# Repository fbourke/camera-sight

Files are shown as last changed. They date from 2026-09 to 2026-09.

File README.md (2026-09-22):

# camera-sight

A 3D-printed open-frame "rifle sight" for a 35 mm cine camera, written in
[OpenSCAD](https://openscad.org/). You look through the rear ring at the front
ring; when the two rings nest concentrically your eye is at the design eye
relief, and the front opening then frames exactly what the lens sees.

The frame is derived from the camera gate (35 mm 4-perf Academy, SMPTE 59) and
the lens focal length, so one file covers every lens: change `f_lens` and
export.

## Mounting

Two clearance holes on the side wall take the finder screws of a Bell & Howell
Eyemo: 0.125" screws on 0.918" centres, set a third of the way back from the
front face. The screws thread into the camera; the sight only needs to clear
them.

The original cold-shoe foot is still in the file behind `with_foot` if you
want it instead.

## Usage

Open `rifle_sight.scad` and set the knobs at the top of the file:

| Parameter | What it does |
| --- | --- |
| `f_lens` | Lens focal length in mm. Sets the frame size and the engraved label. |
| `eye_relief` | Distance from your pupil to the rear face, mm. |
| `with_foot`, `mount_side` | Add the cold-shoe foot, and whether it stands beside or lies under the sight. |
| `label_top` | Engrave the focal length on the top wall (`true`) or the bottom (`false`). |
| `quick` | Skip the filleted body for a faster preview. |

Then render (F6) and export an STL. From the command line:

```sh
openscad -D f_lens=50 -o rifle_sight_50mm.stl rifle_sight.scad
```

The console echoes the frame size and the field of view it subtends, which is
a handy sanity check against the lens.

## Printing

Print with the rear (eye) face down. The webs carrying the front reticle are
angled so their steepest overhang is `90 - a_gusset + a_concave` degrees (65
by default), which prints without support.

Ready-made STLs for 28, 35 and 50 mm lenses are in the repo.

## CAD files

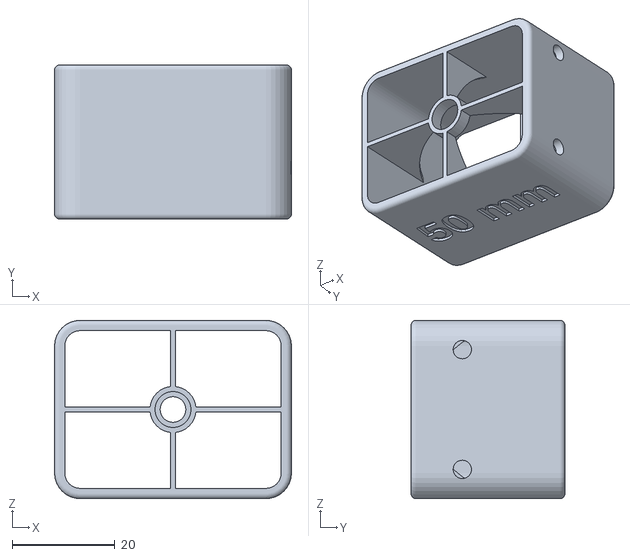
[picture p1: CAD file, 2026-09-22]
rifle_sight_eyemo_50mm.stl
46.1 x 30.0 x 34.7

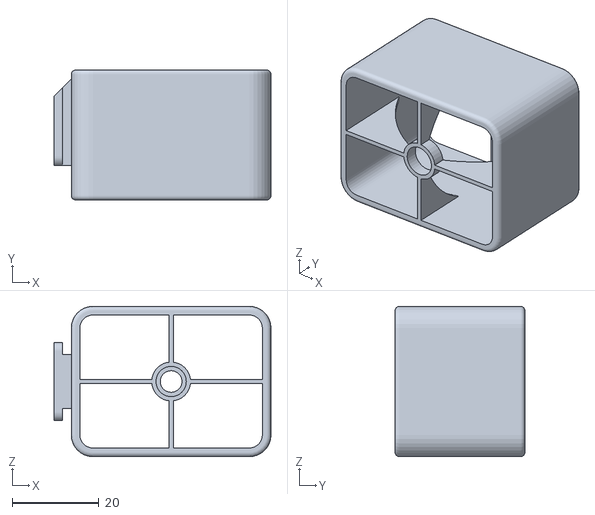
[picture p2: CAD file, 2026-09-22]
rifle_sight_50mm.stl
50.1 x 30.0 x 34.7

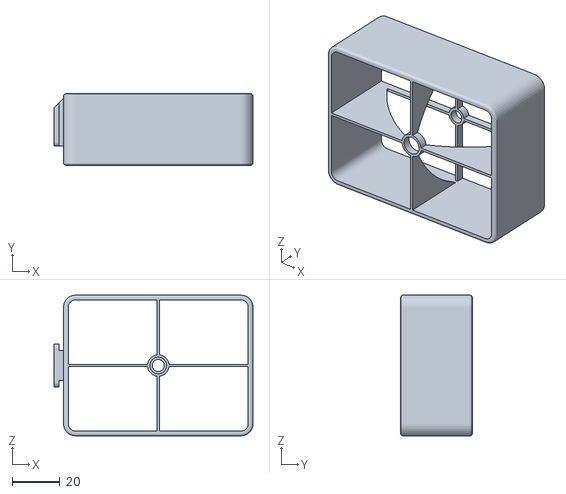
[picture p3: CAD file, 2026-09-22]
rifle_sight_28mm.stl
83.2 x 30.0 x 58.9

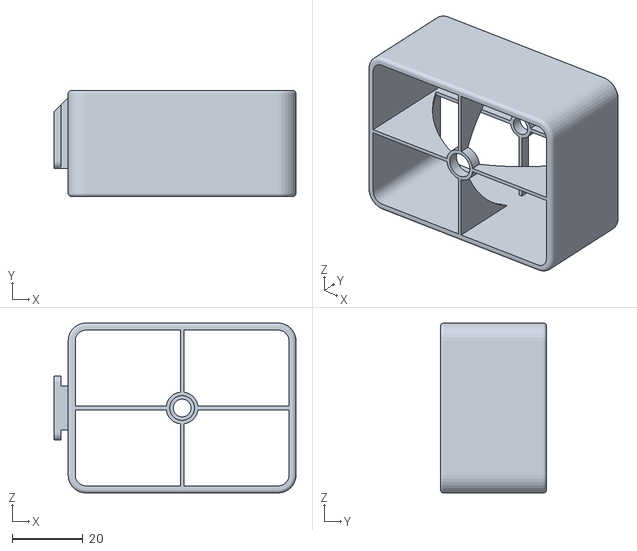
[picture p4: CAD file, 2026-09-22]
rifle_sight_35mm.stl
68.2 x 30.0 x 47.9

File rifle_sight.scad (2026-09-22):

$fn = 32;

quick = false;

// Format: 35 mm 4-perf, Academy camera aperture (SMPTE 59), 1.372:1.
gate_w = 21.95;
gate_h = 16.00;
f_lens = 50;

// Pupil to the rear face. The only ergonomic knob: frame size and front ring both
// scale off it. 66 is what the original 2.5/3.5 ring pair already implied.
eye_relief = 66;

l_sight = 30;
th_sight = 2;
l_offset_sight = l_sight/2 - 12;

// The front opening is the frame, so it must subtend the lens' field from the eye.
// The rear opening is the same size but nearer, so it subtends more and never clips.
d_frame = eye_relief + l_sight;
w_sight = gate_w * d_frame / f_lens;
h_sight = gate_h * d_frame / f_lens;

w_crosshairs = 1;
l_crosshairs = 3;
aperture_r = 2.5;
// Sized so both rings subtend the same angle at the design eye position: they nest
// concentrically only there, which is what holds eye_relief (and the framing) honest.
aperture_f = aperture_r * (d_frame - l_crosshairs/2) / (eye_relief + l_crosshairs/2);

r_fillet = 1;
r_inner_sight = 3;
r_outer_sight = r_inner_sight + th_sight;

// Straight run of the webs under the front reticle, printing rear face down, and how
// far their edge bows in from it. Steepest overhang is 90 - a_gusset + a_concave, so
// a_concave = 0 is a straight 45 deg web and 45 puts the edge tangent to the arm.
a_gusset = 45;
a_concave = 20;

// Cold shoe foot, superseded by the Eyemo holes but kept as an option. Wall it mounts
// on: side stands the plate vertical alongside the sight, otherwise it lies flat
// underneath.
with_foot = false;
mount_side = false;

w_foot = 18.1;
l_foot = 20;
h_foot = 1.99;
r_foot = 2;

w_leg = 12.5;
h_leg = 2;

// Eyemo finder mount: two clearance holes through the side wall away from the shoe,
// one either side of the axis, the pair set l_mount back from the front face. Screws
// thread into the camera, so the holes only need to clear the 0.125" major diameter.
d_mount_screw = 0.125 * 25.4;
d_mount_hole = d_mount_screw + 0.4;
p_mount = 0.918 * 25.4;
l_mount = l_sight/3;

// Focal length engraved in the top wall, reading left to right from the eye. Bottom
// instead puts it where it reads the same way once the sight is turned over.
label_top = false;
s_label = 8;
d_label = 0.6;

echo (str ("frame ", w_sight, " x ", h_sight, " mm at ", d_frame, " mm from the eye"));
echo (str ("fov ", 2 * atan (gate_w / (2 * f_lens)), " x ", 2 * atan (gate_h / (2 * f_lens)), " deg"));
echo (str ("web overhang ", 90 - a_gusset + a_concave, " deg"));

// Sight sits on its own axis, foot swung round to whichever wall it mounts on.
translate ([0, l_sight/2 - l_offset_sight, 0])
    rotate ([90, 0, 0])
        sight (r_fillet);

if (with_foot)
    rotate ([0, mount_side ? 90 : 0, 0])
        translate ([0, 0, - (mount_side ? w_sight : h_sight)/2 - th_sight - h_foot - h_leg])
            foot ();

module foot ()
{
    h_ramp = h_foot + h_leg;

    difference ()
    {
        union ()
        {
            translate ([0, 0, h_foot])
                linear_extrude (h_leg)
                    square ([w_leg, l_foot], center = true);

            linear_extrude (h_foot)
            {
                minkowski ()
                {
                    square ([w_foot - 2* r_foot, l_foot - 2 * r_foot], center = true);
                    circle (r_foot);
                }
            }
        }

        // Lead in on the rear end. Printing rear face down that edge would otherwise
        // start in open air, so taper it to grow off the tube wall at 45 deg.
        rotate ([0, 90, 0])
            linear_extrude (w_foot + 2, center = true)
                polygon ([[1, l_foot/2 + 1],
                          [- h_ramp - 1, l_foot/2 + 1],
                          [1, l_foot/2 - h_ramp - 1]]);
    }
}

module sight (r)
{
    // Pad under the foot's leg.
    if (with_foot)
        rotate ([0, 0, mount_side ? -90 : 0])
        translate ([0, - (mount_side ? w_sight : h_sight)/2 - 0.001, l_sight/2 - l_offset_sight])
            hull ()
            {
                translate ([0, - th_sight + 0.001, 0])
                    cube ([w_leg, 0.001, l_foot], center = true);

                cube ([w_leg, 0.001, l_foot], center = true);
            }

    translate ([0, 0, l_sight - l_crosshairs])
        crosshairs (aperture_f);

    gussets (aperture_f);

    crosshairs (aperture_r);

    difference ()
    {
        sight_body (r);

        translate ([0, 0, -1])
            linear_extrude (l_sight + 2)
                minkowski ()
                {
                    square ([w_sight - 2 * r_inner_sight, h_sight - 2 * r_inner_sight], center = true);
                    circle (r = r_inner_sight);
                }

        mount_holes ();

        label ();
    }
}

// Through the side wall, in the flat between the corner rounds.
module mount_holes ()
{
    for (i = [-1, 1])
        translate ([w_sight/2 - 1, i * p_mount/2, l_sight - l_mount])
            rotate ([0, 90, 0])
                cylinder (d = d_mount_hole, h = th_sight + 2);
}

// Cut into the outer face of the top wall. Rotated so it reads left to right with
// the tops of the letters towards the front when looked down on from the eye.
module label ()
{
    rotate ([0, 0, label_top ? 0 : 180])
    translate ([0, h_sight/2 + th_sight - d_label, l_sight/2])
        rotate ([0, 0, 180])
            rotate ([90, 0, 0])
                linear_extrude (d_label + 1)
                    text (str (f_lens, " mm"), size = s_label, halign = "center", valign = "center",
                          font = "Liberation Sans:style=Bold");
}

module sight_body (rr)
{
    if (!quick)
    {
        hull ()
            for (k=[0, 1])
            {
                translate ([0, 0, rr + k * (l_sight - 2 * rr)])
                {
                    for (i=[-1, 1])
                    {
                        translate ([0, i * (h_sight/2 - r_inner_sight), 0])
                        for (j=[-1, 1])
                        {
                            translate ([j * (w_sight/2 - r_inner_sight), 0, 0])
                                rotate_extrude ()
                                {
                                    translate ([r_outer_sight - rr, 0, 0])
                                        circle (rr);
                                }
                        }
                    }
                }
            }
    }
    else
        linear_extrude (l_sight)
            {

                minkowski ()
                {
                    square ([w_sight - 2 * r_inner_sight, h_sight - 2 * r_inner_sight], center = true);
                    circle (r_outer_sight);
                }
            }
}

// Webs carrying the front reticle back to the rear face, one under each arm. They
// lie in planes through the sight axis, so they grow off the wall at a_gusset and
// sit edge on to the eye behind the arm they support.
module gussets (r)
{
    for (a = [0, 90, 180, 270])
        rotate ([0, 0, a])
            rotate ([90, 0, 0])
                linear_extrude (w_crosshairs, center = true)
                    gusset (r + w_crosshairs, a % 180 == 0 ? w_sight/2 : h_sight/2);
}

// Profile of one web, radius across and sight axis up. Squares off against the rear
// face if a_gusset is too steep to reach the wall in the length available.
module gusset (r_in, r_out)
{
    z0 = l_sight - l_crosshairs;
    dv = (r_out - r_in) * tan (a_gusset);
    c = norm ([r_out - r_in, dv]) / 2;

    difference ()
    {
        intersection ()
        {
            translate ([r_in, 0])
                square ([r_out - r_in, z0]);

            translate ([r_in, z0])
                rotate (- a_gusset)
                    square (w_sight + l_sight);
        }

        // Arc through both ends of the straight edge, bowed in towards the corner.
        if (a_concave > 0)
            let (n = [dv, r_out - r_in] / (2 * c))
                translate ([(r_in + r_out)/2, z0 - dv/2] - c / tan (a_concave) * n)
                    circle (c / sin (a_concave), $fn = 128);
    }
}

module crosshairs (r)
{
    linear_extrude (l_crosshairs)
        difference ()
        {
            union ()
            {
                square ([w_sight, w_crosshairs], center = true);
                square ([w_crosshairs, h_sight], center = true);
                circle (r + w_crosshairs);
            }
            circle (r);
        }
}

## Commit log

2026-09-22 Rifle-style camera sight with Eyemo finder mount
    OpenSCAD open-frame sight scaled from a 35 mm 4-perf Academy gate and lens
    focal length. Two 0.918" on-centre clearance holes for the Eyemo finder
    screws on the side wall, an optional cold-shoe foot, and the focal length
    engraved on the top wall. STL exports for 28, 35 and 50 mm.
    [rifle_sight(4).scad, rifle_sight_28mm.stl, rifle_sight_35mm.stl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]
2026-09-22 Rename source, add README
    [rifle_sight.scad]
